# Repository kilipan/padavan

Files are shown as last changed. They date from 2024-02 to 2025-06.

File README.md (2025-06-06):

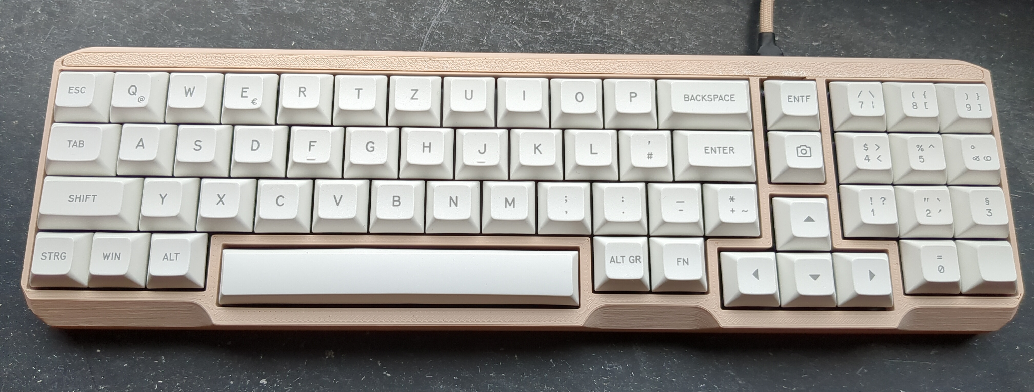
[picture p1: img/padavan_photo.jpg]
padavan


# Padavan
A Minivan keyboard with small numpad and wireless capabilities.

## Layout Options
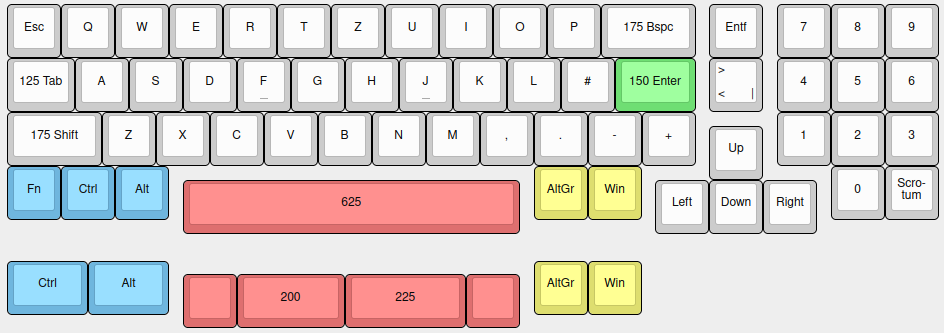
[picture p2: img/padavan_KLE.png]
KLE


An untested southpaw variant can be found in the [`southpaw`](https://github.com/kilipan/padavan/tree/main/southpaw) directory. Use at your own risk!

## BOM
| Amount | Part |
|---:|:-----|
| 1 | Padavan PCB |
| 1 | Pro-Micro compatible MCU board |
|  58-63 | Kailh MX hot swap sockets |
| 1 | Padavan case and plate |
| 10 | Cylindrical magnets (d=3mm, l=2mm) |
| 5 | M2 screws, l=8mm |
| 11 | M2 screws, l=6mm |
| 16 | M2 heat inserts |

If you want to use the Padavan wirelessly, you'll need a wireless-capable controller, like e.g. the [nice!nano](https://nicekeyboards.com/nice-nano/)!

## Firmware
Tested and working [ZMK firmware](https://github.com/kilipan/zmk-config-padavan) is available,
as well as [QMK firmware including Vial](https://github.com/kilipan/qmk-config-padavan).

## Availability
All files are provided under CERN-OHL-S license. Feel free to build your own!

### Case
The fantastic case was designed by DizzySkizzo (`dizzyskizzo1337` on discord). Thank you for letting me use and open source this genius design!
Production files available in [`production/case`](https://github.com/kilipan/padavan/tree/main/production/case).

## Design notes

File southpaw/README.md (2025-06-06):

# Vanapad
A southpaw Minivan keyboard with small numpad and wireless capabilities.

**Untested hardware! Use at your own risk!**

## Layout Options
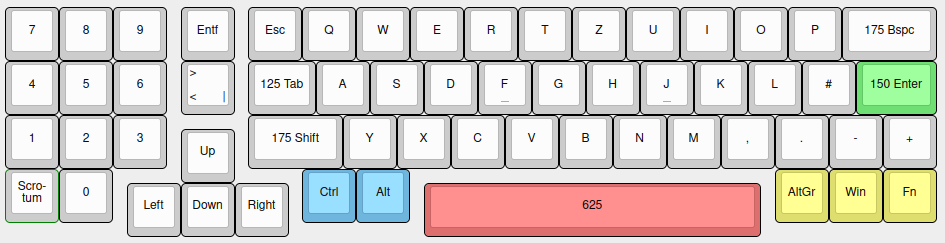
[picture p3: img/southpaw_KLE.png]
KLE


## BOM
| Amount | Part |
|---:|:-----|
| 1 | Vanapad PCB |
| 1 | Vanapad plate |
| 1 | Pro-Micro compatible MCU board |
|  58-63 | Kailh MX hot swap sockets |

If you want to use the Vanapad wirelessly, you'll need a wireless-capable controller, like e.g. the [nice!nano](https://nicekeyboards.com/nice-nano/)!

## Firmware
Not yet available. You can try modifying the padavan firmware!

## Availability
All files are provided under CERN-OHL-S license. Feel free to build your own!

### Case
None available as of the time of writing.

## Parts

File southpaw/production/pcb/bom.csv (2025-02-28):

Designator | Footprint | Quantity | Value | LCSC Part #
D1, D10, D11, D12, D13, D14, D15, D16, D17, D18, D19, D2, D20, D21, D22, D23, D24, D25, D26, D27, D28, D29, D3, D30, D31, D32, D33, D34, D35, D36, D37, D38, D39, D4, D40, D41, D42, D43, D44, D45, D46, D47, D48, D49, D5, D50, D51, D52, D53, D54, D55, D56, D57, D58, D59, D6, D60, D61, D62, D63, D7, D8, D9 | 1206 | 63 | 1N4148
H1, H2, H3, H4, H5, H6 | MountingHole_2.2mm_M2_Pad | 6 | MountingHole_Pad
J1 | JST_GH_SM02B-GHS-TB_1x02-1MP_P1.25mm_Horizontal | 1 | Battery JST
J2 | power-switch_thts | 1 | External Power Switch
J3 | power-thts | 1 | Battery THT
S1 | STAB_MX_P_6.25u | 1 | MX_stab
S2 | STAB_MX_P_2u | 1 | MX_stab
S3 | STAB_MX_P_2.25u | 1 | MX_stab
SW1, SW10, SW11, SW12, SW13, SW14, SW15, SW17, SW18, SW19, SW2, SW22, SW23, SW24, SW25, SW26, SW27, SW28, SW29, SW3, SW30, SW31, SW33, SW34, SW35, SW36, SW38, SW39, SW40, SW41, SW42, SW43, SW44, SW45, SW46, SW47, SW48, SW49, SW5, SW50, SW51, SW52, SW53, SW54, SW55, SW56, SW57, SW58, SW59, SW6, SW64, SW65, SW66, SW67, SW7, SW8, SW9 | SW_MX_HS_1u | 57 | MX_SW_HS
SW16, SW37 | SW_MX_HS_1.75u | 2 | MX_SW_HS
SW20, SW4 | SW_MX_1u | 2 | MX_SW_HS
SW21 | SW_MX_HS_1.25u | 1 | MX_SW_HS
SW32 | SW_MX_HS_1.5u | 1 | MX_SW_HS
SW60, SW61 | SW_MX_HS_CPG151101S11_1.5u | 2 | MX_SW_HS
SW62 | SW_SPDT_PCM12 | 1 | On-Board Power Switch
SW63 | SW_ResetSW | 1 | SW_Push
U1 | nice_nano_AH_USBup | 1 | nice_nano

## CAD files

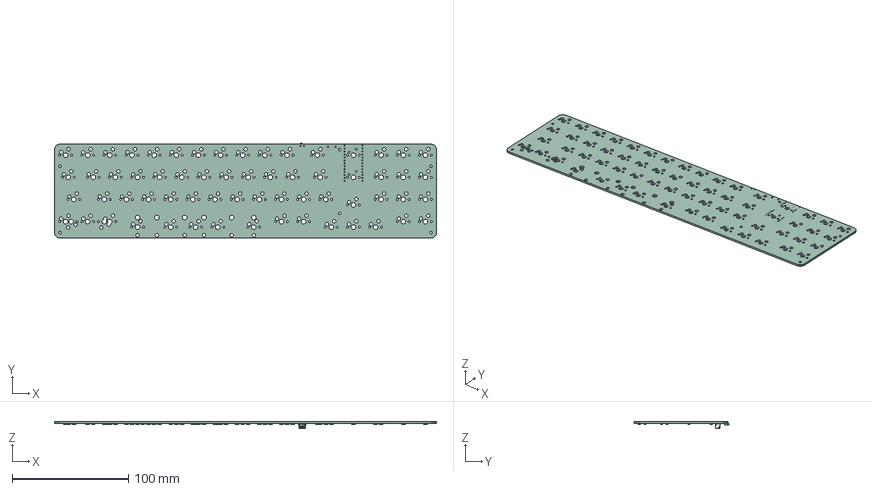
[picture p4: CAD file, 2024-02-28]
kicad_padavan.step
328.6 x 82.1 x 5.89 mm
padavan PCB

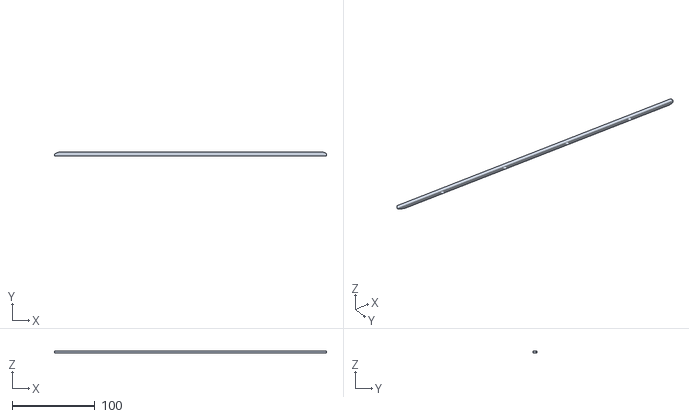
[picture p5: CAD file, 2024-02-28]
production/case/Padavan R1/accent.stl
329.7 x 5.22 x 2.89

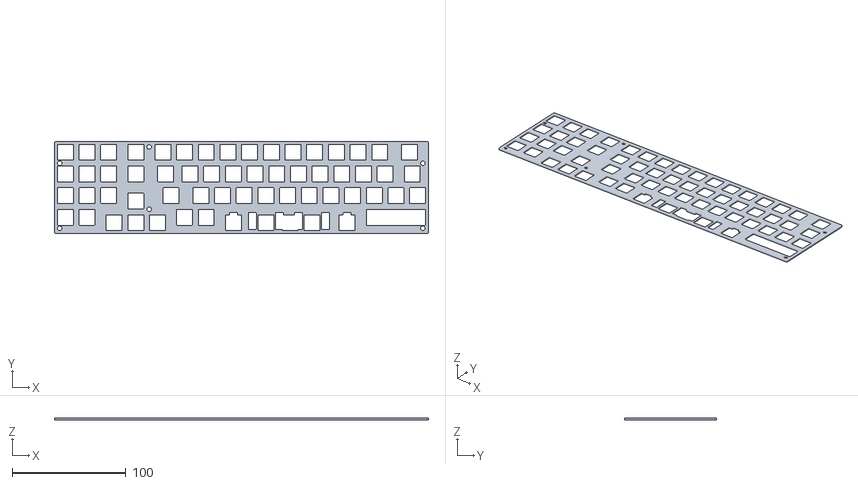
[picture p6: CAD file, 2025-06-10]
southpaw/production/vanapadplate.stl
328.6 x 81.0 x 1.50

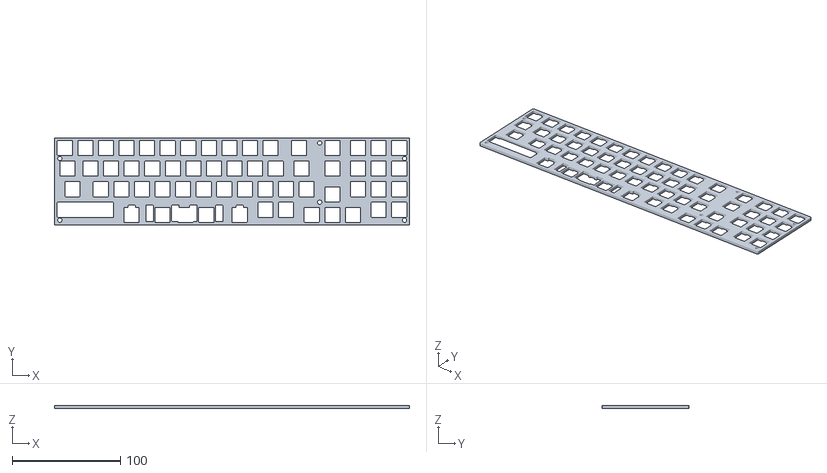
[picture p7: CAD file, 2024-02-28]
production/case/Padavan R1/padavanplate_3mm_plate.STL
328.6 x 81.0 x 3.00

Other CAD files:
production/case/Padavan R1/padavanplate.stl
production/case/Padavan R1/padavanplate.dxf

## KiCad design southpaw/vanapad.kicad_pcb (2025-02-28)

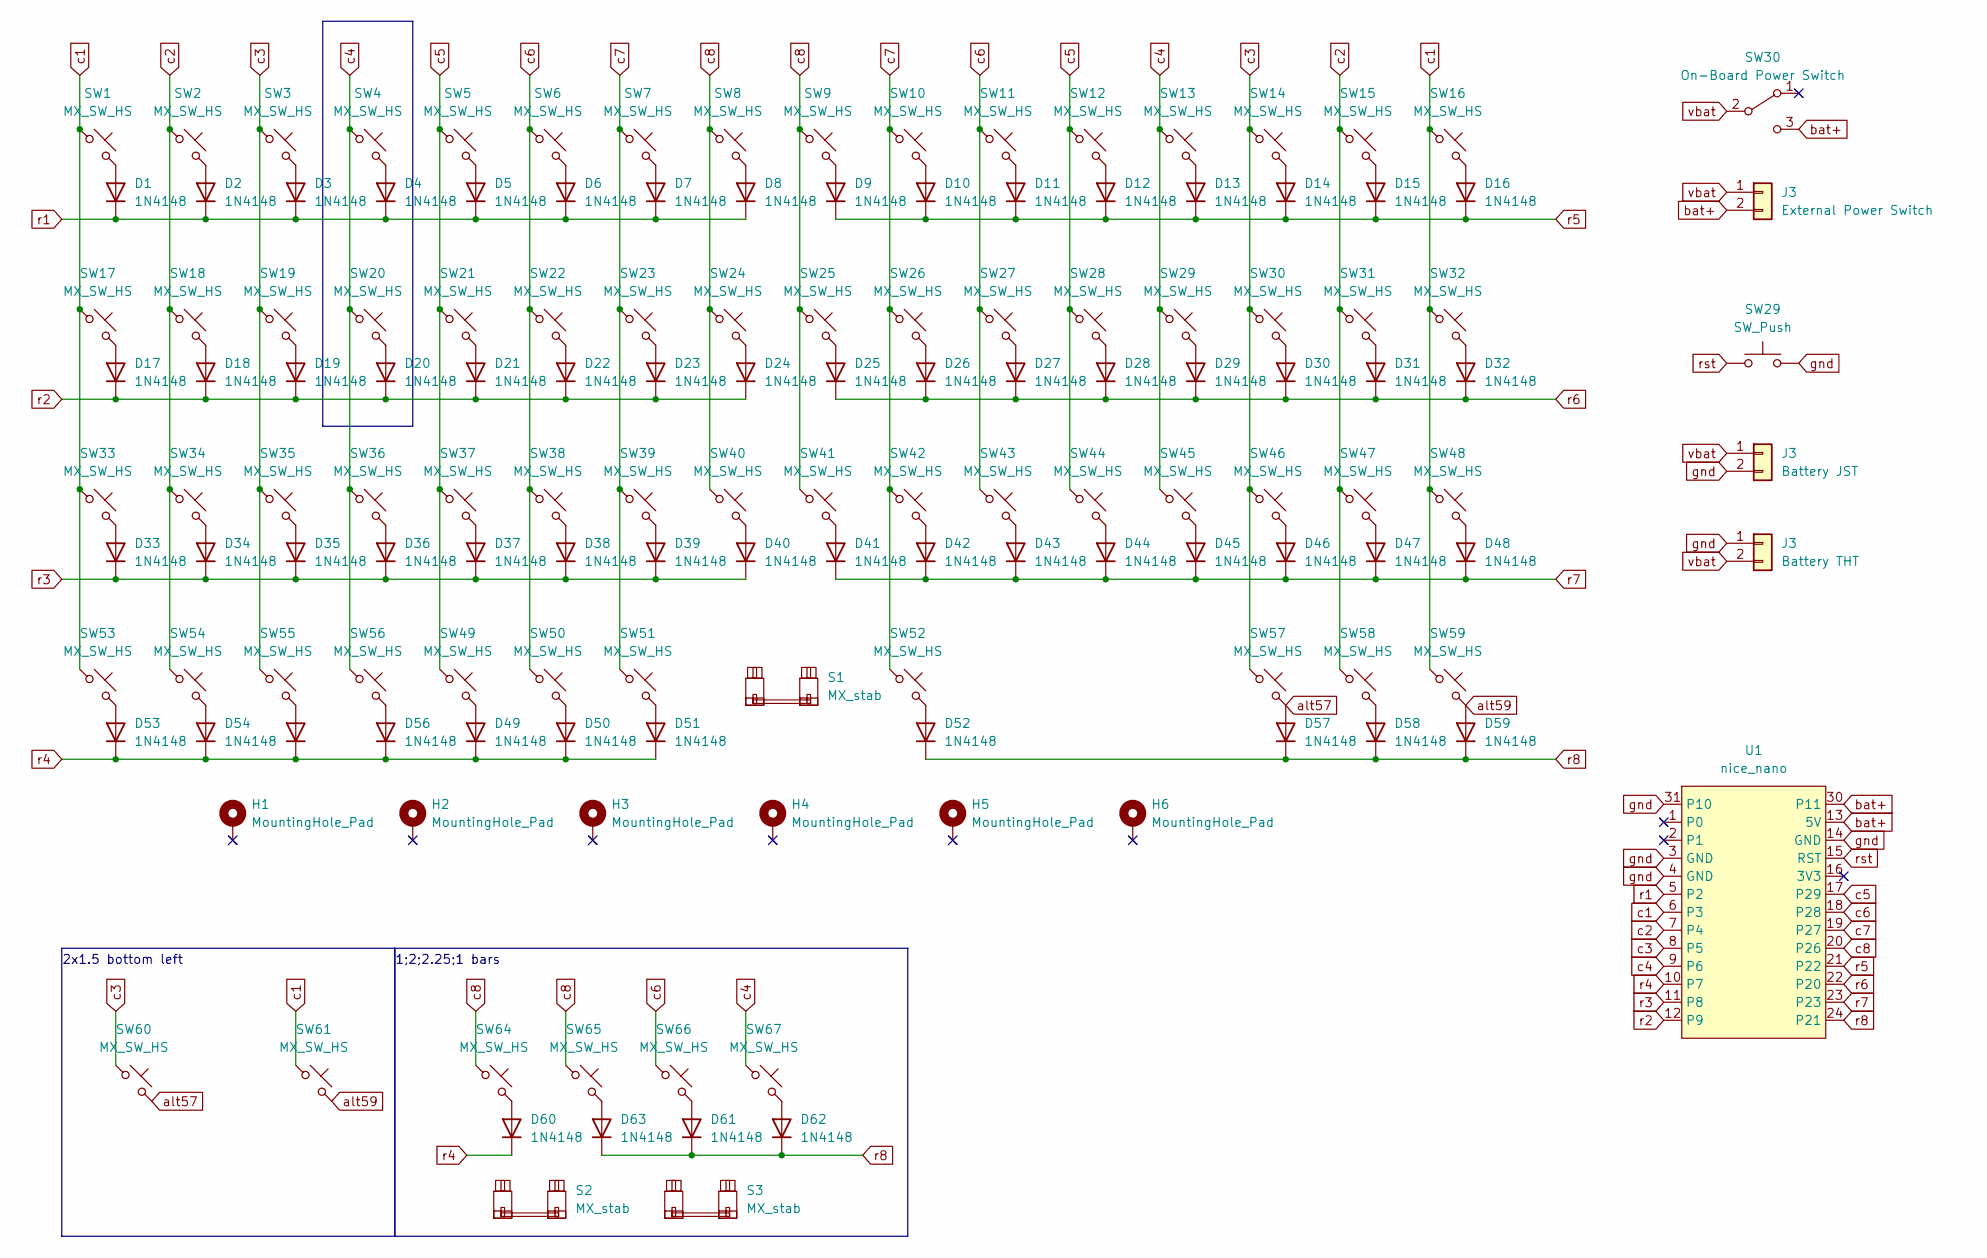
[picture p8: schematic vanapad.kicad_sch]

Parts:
D1, D2, D3, D4, D5, D6, D7, D8, D9, D10, D11, D12, D13, D14, D15, D16, D17, D18, D19, D20, D21, D22, D23, D24, D25, D26, D27, D28, D29, D30, D31, D32, D33, D34, D35, D36, D37, D38, D39, D40, D41, D42, D43, D44, D45, D46, D47, D48, D49, D50, D51, D52, D53, D54, D55, D56, D57, D58, D59, D60, D61, D62, D63: 1N4148; D_1206_3216Metric_Pad1.42x1.75mm_HandSolder
H1, H2, H3, H4, H5, H6: MountingHole_Pad; MountingHole_2.2mm_M2_Pad
J3: External Power Switch; power-switch_thts
S1: MX_stab; STAB_MX_P_6.25u
S2: MX_stab; STAB_MX_P_2u
S3: MX_stab; STAB_MX_P_2.25u
SW1, SW2, SW3, SW5, SW6, SW7, SW8, SW9, SW10, SW11, SW12, SW13, SW14, SW15, SW17, SW18, SW19, SW22, SW23, SW24, SW25, SW26, SW27, SW28, SW29, SW31, SW33, SW34, SW35, SW36, SW38, SW39, SW40, SW41, SW42, SW43, SW44, SW45, SW46, SW47, SW48, SW49, SW50, SW51, SW52, SW53, SW54, SW55, SW56, SW57, SW58, SW59, SW64, SW65, SW66, SW67: MX_SW_HS; SW_MX_HS_1u
SW4, SW20: MX_SW_HS; SW_MX_1u
SW16, SW37: MX_SW_HS; SW_MX_HS_1.75u
SW21: MX_SW_HS; SW_MX_HS_1.25u
SW30: On-Board Power Switch; SW_SPDT_PCM12
SW32: MX_SW_HS; SW_MX_HS_1.5u
SW60, SW61: MX_SW_HS; SW_MX_HS_CPG151101S11_1.5u
U1: nice_nano; nice_nano_AH_USBup

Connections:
unnamed: D1.2 (A), SW1.2
unnamed: D2.2 (A), SW2.2
unnamed: D3.2 (A), SW3.2
unnamed: D4.2 (A), SW4.2
unnamed: D5.2 (A), SW5.2
unnamed: D6.2 (A), SW6.2
unnamed: D7.2 (A), SW7.2
unnamed: D8.2 (A), SW8.2
unnamed: D9.2 (A), SW9.2
unnamed: D10.2 (A), SW10.2
unnamed: D11.2 (A), SW11.2
unnamed: D12.2 (A), SW12.2
unnamed: D13.2 (A), SW13.2
unnamed: D14.2 (A), SW14.2
unnamed: D15.2 (A), SW15.2
unnamed: D16.2 (A), SW16.2
unnamed: D17.2 (A), SW17.2
unnamed: D18.2 (A), SW18.2
unnamed: D19.2 (A), SW19.2
unnamed: D20.2 (A), SW20.2
unnamed: D21.2 (A), SW21.2
unnamed: D22.2 (A), SW22.2
unnamed: D23.2 (A), SW23.2
unnamed: D24.2 (A), SW24.2
unnamed: D25.2 (A), SW25.2
unnamed: D26.2 (A), SW26.2
unnamed: D27.2 (A), SW27.2
unnamed: D28.2 (A), SW28.2
unnamed: D31.2 (A), SW31.2
unnamed: D32.2 (A), SW32.2
unnamed: D33.2 (A), SW33.2
unnamed: D34.2 (A), SW34.2
unnamed: D35.2 (A), SW35.2
unnamed: D36.2 (A), SW36.2
unnamed: D37.2 (A), SW37.2
unnamed: D38.2 (A), SW38.2
unnamed: D39.2 (A), SW39.2
unnamed: D40.2 (A), SW40.2
unnamed: D41.2 (A), SW41.2
unnamed: D42.2 (A), SW42.2
unnamed: D43.2 (A), SW43.2
unnamed: D44.2 (A), SW44.2
unnamed: D45.2 (A), SW45.2
unnamed: D46.2 (A), SW46.2
unnamed: D47.2 (A), SW47.2
unnamed: D48.2 (A), SW48.2
unnamed: D49.2 (A), SW49.2
unnamed: D50.2 (A), SW50.2
unnamed: D51.2 (A), SW51.2
unnamed: D52.2 (A), SW52.2
unnamed: D53.2 (A), SW53.2
unnamed: D54.2 (A), SW54.2
unnamed: D55.2 (A), SW55.2
unnamed: D56.2 (A), SW56.2
unnamed: D58.2 (A), SW58.2
unnamed: D60.2 (A), SW64.2
unnamed: D61.2 (A), SW66.2
unnamed: D62.2 (A), SW67.2
unnamed: D63.2 (A), SW65.2
alt57: D57.2 (A), SW57.2, SW60.2
alt59: D59.2 (A), SW59.2, SW61.2
c1: SW1.1, SW16.1, SW17.1, SW32.1, SW33.1, SW48.1, SW53.1, SW59.1, SW61.1, U1.6 (P3)
c2: SW2.1, SW15.1, SW18.1, SW31.1, SW34.1, SW47.1, SW54.1, SW58.1, U1.7 (P4)
c3: SW3.1, SW14.1, SW19.1, SW30.1, SW35.1, SW46.1, SW55.1, SW57.1, SW60.1, U1.8 (P5)
c5: SW5.1, SW12.1, SW21.1, SW28.1, SW37.1, SW44.1, SW49.1, U1.17 (P29)
c6: SW6.1, SW11.1, SW22.1, SW27.1, SW38.1, SW43.1, SW50.1, SW66.1, U1.18 (P28)
c7: SW7.1, SW10.1, SW23.1, SW26.1, SW39.1, SW42.1, SW51.1, SW52.1, U1.19 (P27)
c8: SW8.1, SW9.1, SW24.1, SW25.1, SW40.1, SW41.1, SW64.1, SW65.1, U1.20 (P26)
r1: D1.1 (K), D2.1 (K), D3.1 (K), D4.1 (K), D5.1 (K), D6.1 (K), D7.1 (K), D8.1 (K), U1.5 (P2)
r2: D17.1 (K), D18.1 (K), D19.1 (K), D20.1 (K), D21.1 (K), D22.1 (K), D23.1 (K), D24.1 (K), U1.12 (P9)
r3: D33.1 (K), D34.1 (K), D35.1 (K), D36.1 (K), D37.1 (K), D38.1 (K), D39.1 (K), D40.1 (K), U1.11 (P8)
r4: D49.1 (K), D50.1 (K), D51.1 (K), D53.1 (K), D54.1 (K), D55.1 (K), D56.1 (K), D60.1 (K), U1.10 (P7)
r5: D9.1 (K), D10.1 (K), D11.1 (K), D12.1 (K), D13.1 (K), D14.1 (K), D15.1 (K), D16.1 (K), U1.21 (P22)
r6: D25.1 (K), D26.1 (K), D27.1 (K), D28.1 (K), D29.1 (K), D30.1 (K), D31.1 (K), D32.1 (K), U1.22 (P20)
r7: D41.1 (K), D42.1 (K), D43.1 (K), D44.1 (K), D45.1 (K), D46.1 (K), D47.1 (K), D48.1 (K), U1.23
r8: D52.1 (K), D57.1 (K), D58.1 (K), D59.1 (K), D61.1 (K), D62.1 (K), D63.1 (K), U1.24 (P21)

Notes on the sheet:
1;2;2.25;1 bars
2x1.5 bottom left

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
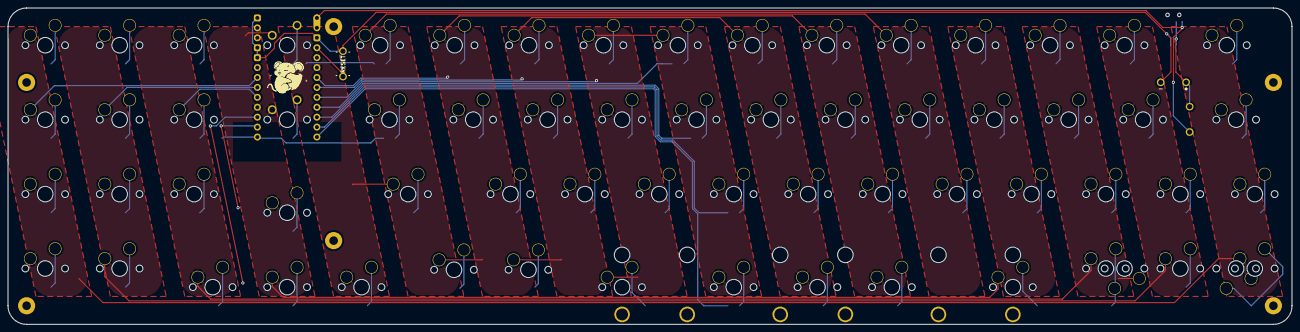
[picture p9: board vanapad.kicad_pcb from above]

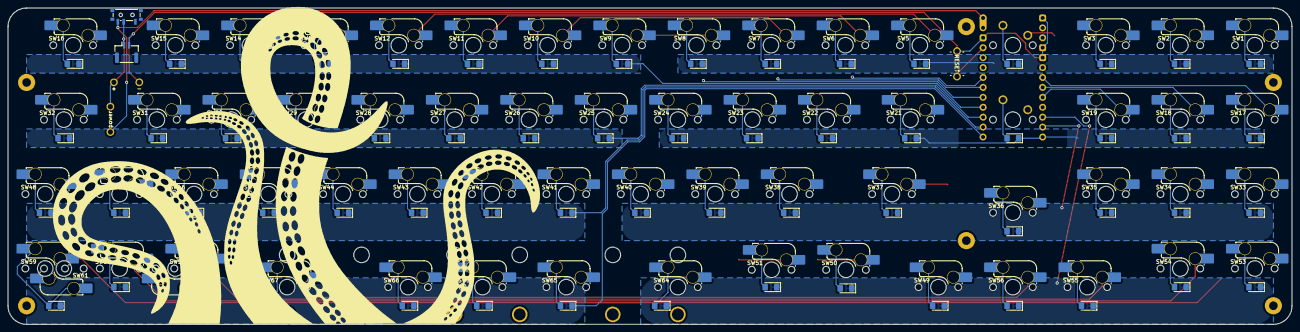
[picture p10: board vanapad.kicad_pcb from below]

Board: 2 copper layers, 328.6 x 81.0 mm, 143 parts (131 on the bottom side), 83 nets.

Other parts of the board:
J1: Battery JST; JST_GH_SM02B-GHS-TB_1x02-1MP_P1.25mm_Horizontal
J2: External Power Switch; power-switch_thts
SW62: On-Board Power Switch; SW_SPDT_PCM12
SW63: SW_Push; SW_ResetSW

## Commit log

2024-02-28 provide unzipped case files
    [accent.stl, padavanplate.dxf, padavanplate.stl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]
2025-02-28 add untested vanapad files
    [bom.csv, designators.csv, positions.csv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]
2025-02-28 fix alternative bottom row routing
    [bom.csv, vanapad.kicad_pcb, vanapad.kicad_sch]
2025-02-28 make vanapad pcb compatible with mirrored case
    [vanapad.kicad_pcb]
2025-06-06 feat: add case hardware to BOM
2025-06-10 feat: add vanapad plate
    [bom.csv, designators.csv, positions.csv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]
